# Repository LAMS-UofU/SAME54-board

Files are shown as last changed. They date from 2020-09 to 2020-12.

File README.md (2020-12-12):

# LAMS 

In these files, you will find the software, datasheets and PCB design for the LAMS project. We integrated multiple peripherals to use with our needed devices such as: timers for the servo PWM signal, UART communications for the LiDAR, simple GPIO signals for a status LED, as well as a simple SysTick configuration to give precise timing measurements. 

## Pinouts

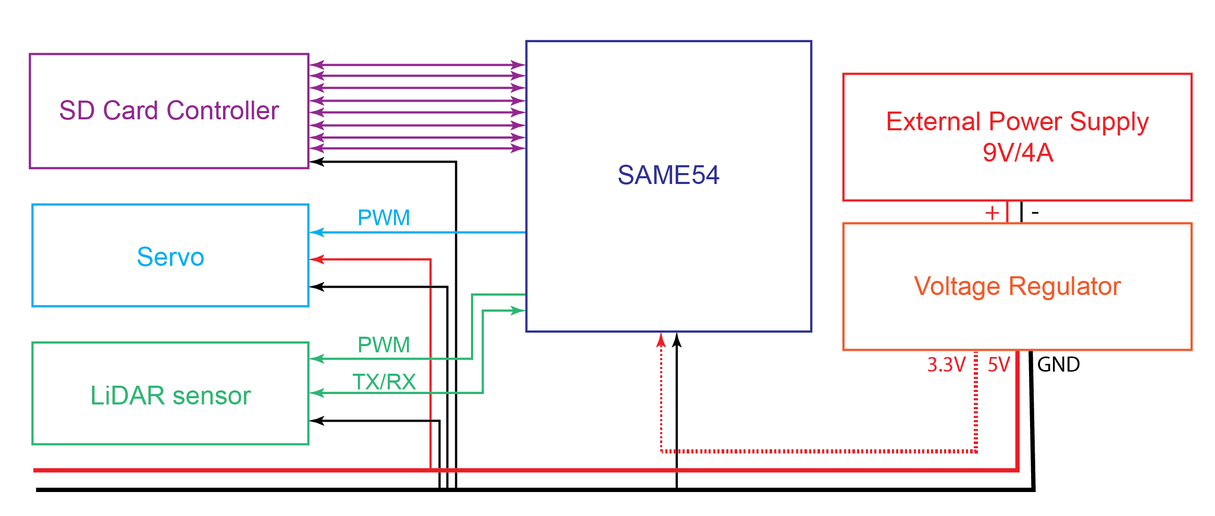
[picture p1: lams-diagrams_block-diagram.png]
Block Diagram


LiDAR: Tx (PA04) / Rx (PA05) / PWM (PB09) <br>
Servo: PWM (PA07) <br>
SD Card: CMD (PA20) / CLK (PA21) / DAT0 (PB18) / DAT1 (PB19) / DAT2 (PB20) / DAT3 (PB21) / CD (PD20) / WP (PD21) <br>
Status LED: PA06 <br>
Start Button: PA27 <br>

## Resources

### SAME54

[SAM D5X/E5X Family Datasheet](http://ww1.microchip.com/downloads/en/DeviceDoc/SAM_D5xE5x_Family_Data_Sheet_DS60001507F.pdf) <br>
[SAM E54 Xplained Pro User's Guide](http://ww1.microchip.com/downloads/en/DeviceDoc/70005321A.pdf)

### Peripherals

[RPLiDAR A2M8 Datasheet](https://cdn.sparkfun.com/assets/e/a/f/9/8/LD208_SLAMTEC_rplidar_datasheet_A2M8_v1.0_en.pdf) <br>
[RPLiDAR A2M8 Communications Protocol v1.0](https://www.robotshop.com/media/files/pdf2/rpk-02-communication-protocol.pdf) <br>
[RPLiDAR A2M8 Communications Protocol v2.1](http://bucket.download.slamtec.com/ccb3c2fc1e66bb00bd4370e208b670217c8b55fa/LR001_SLAMTEC_rplidar_protocol_v2.1_en.pdf) <br>
[SPT5435-180 Specifications](http://www.spt-servo.com/Product/015234339.html)

### MISC

[ASF4 API Reference Manual](http://ww1.microchip.com/downloads/en/DeviceDoc/50002633B.pdf)

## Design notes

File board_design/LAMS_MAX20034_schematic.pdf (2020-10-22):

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

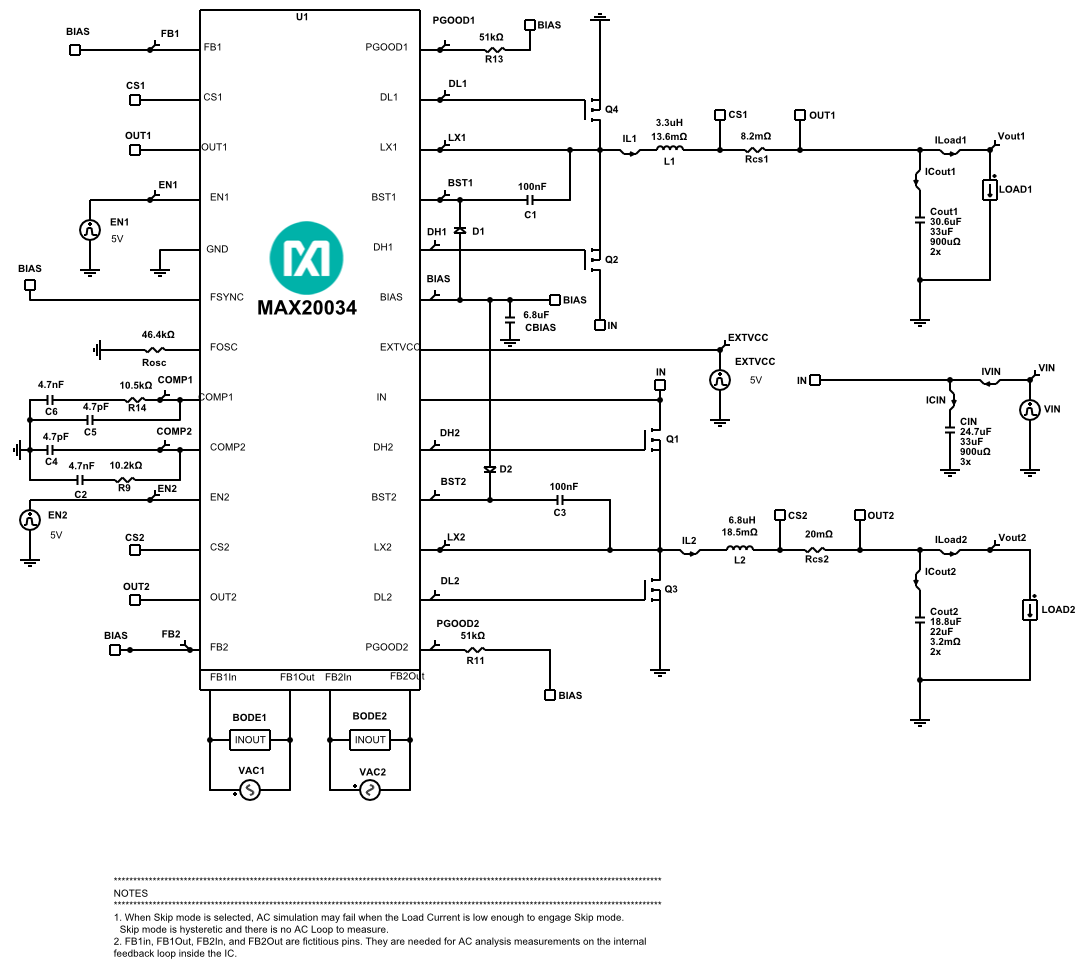
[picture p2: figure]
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

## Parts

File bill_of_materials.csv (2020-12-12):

Ref Part | Quantity | Mouser Part # | Manufacturer Part # | Manufacturer | Description
IC1 | 1 | 556-ATSAME54N20AAUT | ATSAME54N20A-AUT | Microchip | ARM Microcontrollers - MCU 120MHZ 1024KB FLASH 100 TQFP PKG IN 85C
U1 | 1 | 700-MAX20034ATIR/VY+ | MAX20034ATIR/VY+ | Maxim Integrated | 2.2MHz, 36V, Dual Buck Controller with 17Î¼A Quiescent Current
OSC1 | 1 | 581-CX3225CA12DKPSC1 | CX3225CA12000D0KPSC1. | Kyocera | Crystals 12MHz 8pF 3.2x2.5x0.8mm
J1 | 1 | 490-PJ-070BH-SMT-TR | PJ-070BH-SMT-TR | CUI Devices | DC Power Connectors power jack, 2.5 x 5.5 mm, vertical, SMT, high current, 1 switch, T&R package
SD_CARD_CONN | 1 | 523-GSD09002SEU | GSD09002SEU | Amphenol | Memory Card Connectors SD, 9 pos, 15U
RESET_BTN, START_BTN | 2 | 612-LL3301BF065QJ | LL3301BF065QJ | E-Switch | Pushbutton Switches 50mA 12VDC F065 9.5mm J-Lead
C5,C6,C7,C8,C10,C11,C15,C16 | 8 | 80-C0603C104K5R | C0603C104K5RACTU | KEMET Corporation | Cap Ceramic 100nF 50V X7R 10% Pad SMD 0603 125Â°C T/R
C1,C4 | 2 | 80-C0603C472J5R | C0603C472J5RACTU | KEMET Corporation | Cap Ceramic 4.7nF 50V X7R 5% Pad SMD 0603 125Â°C T/R
C2,C3 | 2 | 581-04025A4R7JAT2A | 04025A4R7JAT2A | AVX | Cap Ceramic 4.7pF 50V C0G 5% Pad SMD 0402 125Â°C T/R
C9 | 1 | 81-GRM188R61E106KA3D | GRM188R61E106KA73D | Murata Electronics | Multilayer Ceramic Capacitors MLCC - SMD/SMT 10UF 25V 10% 0603
C12,C13 | 2 | 81-GRM1885C1H8R0CA1D | GRM1885C1H8R0CA01D | Murata Electronics | Multilayer Ceramic Capacitors MLCC - SMD/SMT 8pF 0603
C14 | 1 | 81-GRM188R61C475KAJD | GRM188R61C475KAAJD | Murata Electronics | Multilayer Ceramic Capacitors MLCC - SMD/SMT 0603 4.7uF 16volts *Derate Voltage/Temp
CBIAS | 1 | 80-C1206C685K4R | C1206C685K4RACTU | KEMET Corporation | Cap Ceramic 6.8uF 16V X7R 10% Pad SMD 1206 125Â°C T/R
COUT1, CIN | 5 | 810-C4532X7R1C336M | C4532X7R1C336M250KC | TDK | Multilayer Ceramic Capacitors MLCC - SMD/SMT 1812 16V 33uF X7R 20% T: 2.5mm
COUT2 | 2 | 81-GRM31CR71A226ME5L | GRM31CR71A226ME15L | Murata Manufacturing | Cap 22uF 10V X7R 1206 20% 3.2mOhm 0.72nH Active
D1,D2 | 2 | 863-MBRS140T3G | MBRS140T3G | ON Semiconductor | Rectifier Diode Schottky Si 40V 1A 2-Pin SMB T/R
LED_STATUS | 1 | 710-155060VS75300 | 155060VS75300 | Wurth Elektronik | Standard LEDs - SMD WL-SMSW Wtrclr SdVw Grn 2V 20mA 572nm
LED_RX,LED_TX | 2 | 710-155060AS75300 | 155060VS75301 | Wurth Elektronik | Standard LEDs - SMD WL-SMSW Wtrclr SdVw Amber 2V 20mA 610nm
L1 | 1 | 652-SRP1238A-3R3M | SRP1238A-3R3M | Bourns | Fixed Inductors 3.3uH 20% SMD 1238 AEC-Q200
L2 | 1 | 994-MSS1260-682MLB | MSS1260-682MLB | Coilcraft | Inductor 6.8 uH 20% 18.5mOhm max 3.8Arms @20C 5.9Arms @40C 7.4Asat @-10% 8.26Asat @-20% 8.8Asat @-30% 6.2mmHt 151.29mm^2 MSS1260 Active
M1,M2,M3,M4 | 4 | 863-NVMFS5C468NLFT1G | NVMFS5C468NLAFT1G | On Semi | MOSFET T6 40V NCH LL IN SO8FL
R1 | 1 | 667-ERJ-2RKF1022X | ERJ-2RKF1022X | Panasonic | Res Thick Film 0402 10.2K Ohm 1% 0.1W(1/10W) Â±100ppm/Â°C Pad SMD Automotive T/R
R3,R4 | 2 | 667-ERJ-2GEJ513X | ERJ2GEJ513X | Panasonic | Res Thick Film 0402 51K Ohm 5% 0.1W(1/10W) Â±200ppm/Â°C Pad SMD Automotive T/R
R2 | 1 | 667-ERJ-2RKF1052X | ERJ2RKF1052X | Panasonic | Res Thick Film 0402 10.5K Ohm 1% 0.1W(1/10W) Â±100ppm/Â°C Pad SMD Automotive T/R
R5 | 1 | 667-ERJ-UP3F3300V | ERJ-UP3F3300V | Panasonic | Thick Film Resistors - SMD 0603 0.25W 1% 330ohm AEC-Q200
R6,R8,R12,R13,R15 | 5 | 667-ERJ-UP3F1002V | ERJ-UP3F1002V | Panasonic | Thick Film Resistors - SMD 0603 0.25W 1% 10Kohm AEC-Q200
R7,R9,R10,R11 | 4 | 667-ERJ-PA3F1003V | ERJ-PA3F1003V | Panasonic | Thick Film Resistors - SMD 0603 100Kohm 1% Anti-Surge AEC-Q200
R14 | 1 | 667-ERJ-PA3F1001V | ERJ-PA3F1001V | Panasonic | Thick Film Resistors - SMD 0603 1Kohm 1% Anti-Surge AEC-Q200
R16,R17,R18 | 3 | 667-ERJ-UP3J101V | ERJ-UP3J101V | Panasonic | Thick Film Resistors - SMD 0603 0.25W 5% 100ohm AEC-Q200
RCS1 | 1 | 667-ERJ-3LWFR010V | ERJ-3LWFR010V | Panasonic | Current Sense Resistors - SMD 0603 10mOhms 1% Curr Sens AEC-Q200
RCS2 | 1 | 667-ERJ-8BWFR020V | ERJ8BWFR020V | Panasonic | Res Thick Film 1206 0.02 Ohm 1% 1W 0ppm/Â°C to 150ppm/Â°C Pad SMD Automotive T/R
ROSC | 1 | 667-ERJ-2RKF4642X | ERJ2RKF4642X | Panasonic | Res Thick Film 0402 46.4K Ohm 1% 0.1W(1/10W) Â±100ppm/Â°C Pad SMD Automotive T/R

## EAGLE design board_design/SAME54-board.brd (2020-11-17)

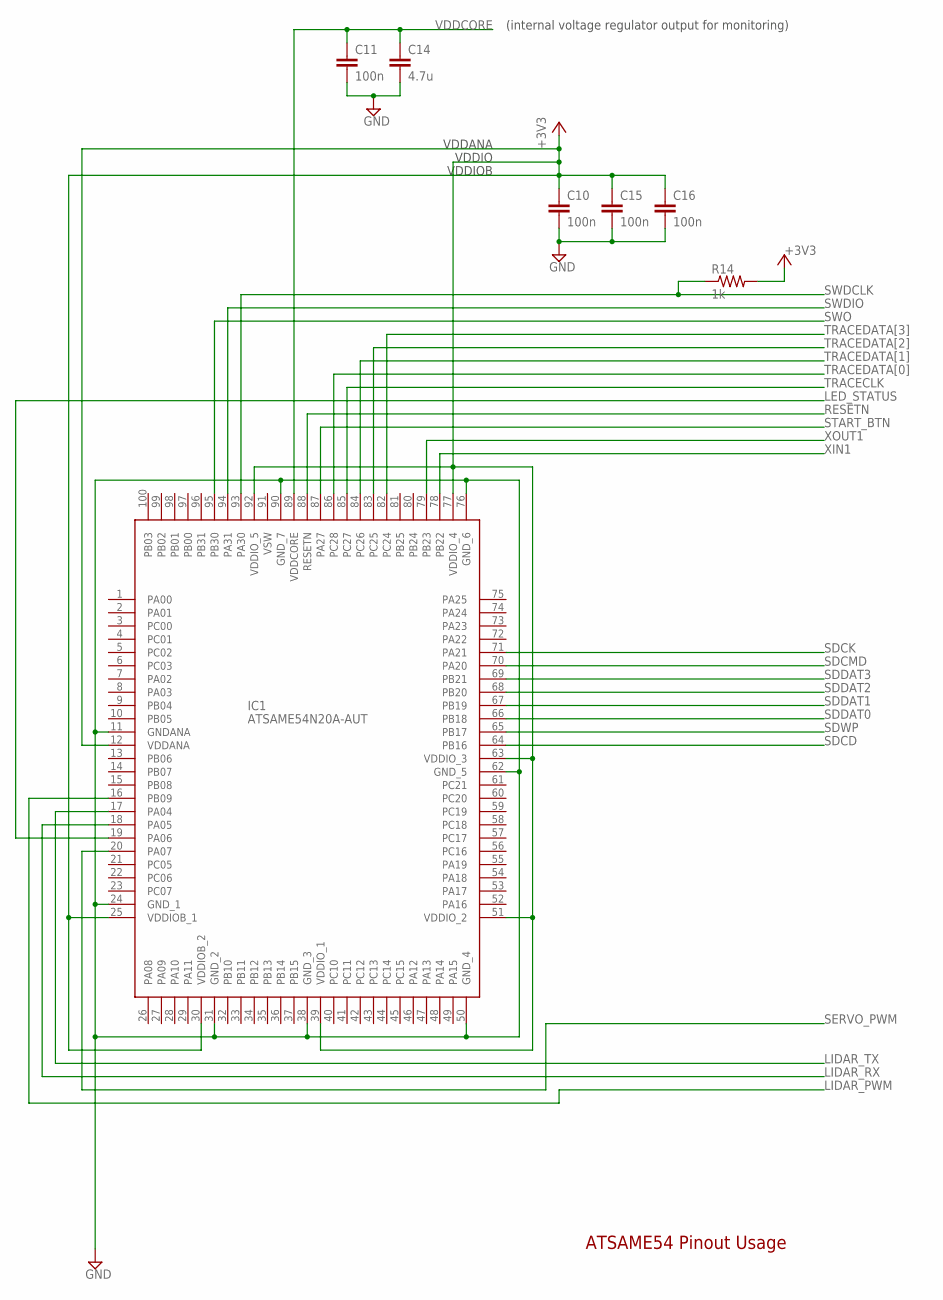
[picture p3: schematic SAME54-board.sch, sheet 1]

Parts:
C10, C11, C15, C16: 100n; C0603
C14: 4.7u; C0603
IC1: ATSAME54N20A-AUT; QFP50P1600X1600X120-100N
R14: 1k; R0603

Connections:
+3V3: C10.1, C15.1, C16.1, IC1.12 (VDDANA), IC1.25 (VDDIOB_1), IC1.30 (VDDIOB_2), IC1.39 (VDDIO_1), IC1.51 (VDDIO_2), IC1.63 (VDDIO_3), IC1.77 (VDDIO_4), IC1.92 (VDDIO_5), R14.2; also elsewhere on the board
GND: C10.2, C11.2, C14.2, C15.2, C16.2, IC1.11 (GNDANA), IC1.24 (GND_1), IC1.31 (GND_2), IC1.38 (GND_3), IC1.50 (GND_4), IC1.62 (GND_5), IC1.76 (GND_6), IC1.90 (GND_7); also elsewhere on the board
LED_STATUS: IC1.19 (PA06); also elsewhere on the board
LIDAR_PWM: IC1.16 (PB09); also elsewhere on the board
LIDAR_RX: IC1.18 (PA05); also elsewhere on the board
LIDAR_TX: IC1.17 (PA04); also elsewhere on the board
RESETN: IC1.88 (RESETN); also elsewhere on the board
SDCD: IC1.64 (PB16); also elsewhere on the board
SDCK: IC1.71 (PA21); also elsewhere on the board
SDCMD: IC1.70 (PA20); also elsewhere on the board
SDDAT0: IC1.66 (PB18); also elsewhere on the board
SDDAT1: IC1.67 (PB19); also elsewhere on the board
SDDAT2: IC1.68 (PB20); also elsewhere on the board
SDDAT3: IC1.69 (PB21); also elsewhere on the board
SDWP: IC1.65 (PB17); also elsewhere on the board
SERVO_PWM: IC1.20 (PA07); also elsewhere on the board
START_BTN: IC1.87 (PA27); also elsewhere on the board
SWDCLK: IC1.93 (PA30), R14.1; also elsewhere on the board
SWDIO: IC1.94 (PA31); also elsewhere on the board
SWO: IC1.95 (PB30); also elsewhere on the board
TRACECLK: IC1.85 (PC27); also elsewhere on the board
TRACEDATA[0]: IC1.86 (PC28); also elsewhere on the board
TRACEDATA[1]: IC1.84 (PC26); also elsewhere on the board
TRACEDATA[2]: IC1.83 (PC25); also elsewhere on the board
TRACEDATA[3]: IC1.82 (PC24); also elsewhere on the board
VDDCORE: C11.1, C14.1, IC1.89 (VDDCORE)
XIN1: IC1.78 (PB22); also elsewhere on the board
XOUT1: IC1.79 (PB23); also elsewhere on the board

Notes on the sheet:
ATSAME54 Pinout Usage
(internal voltage regulator output for monitoring)
VDDANA
VDDIO
VDDIOB

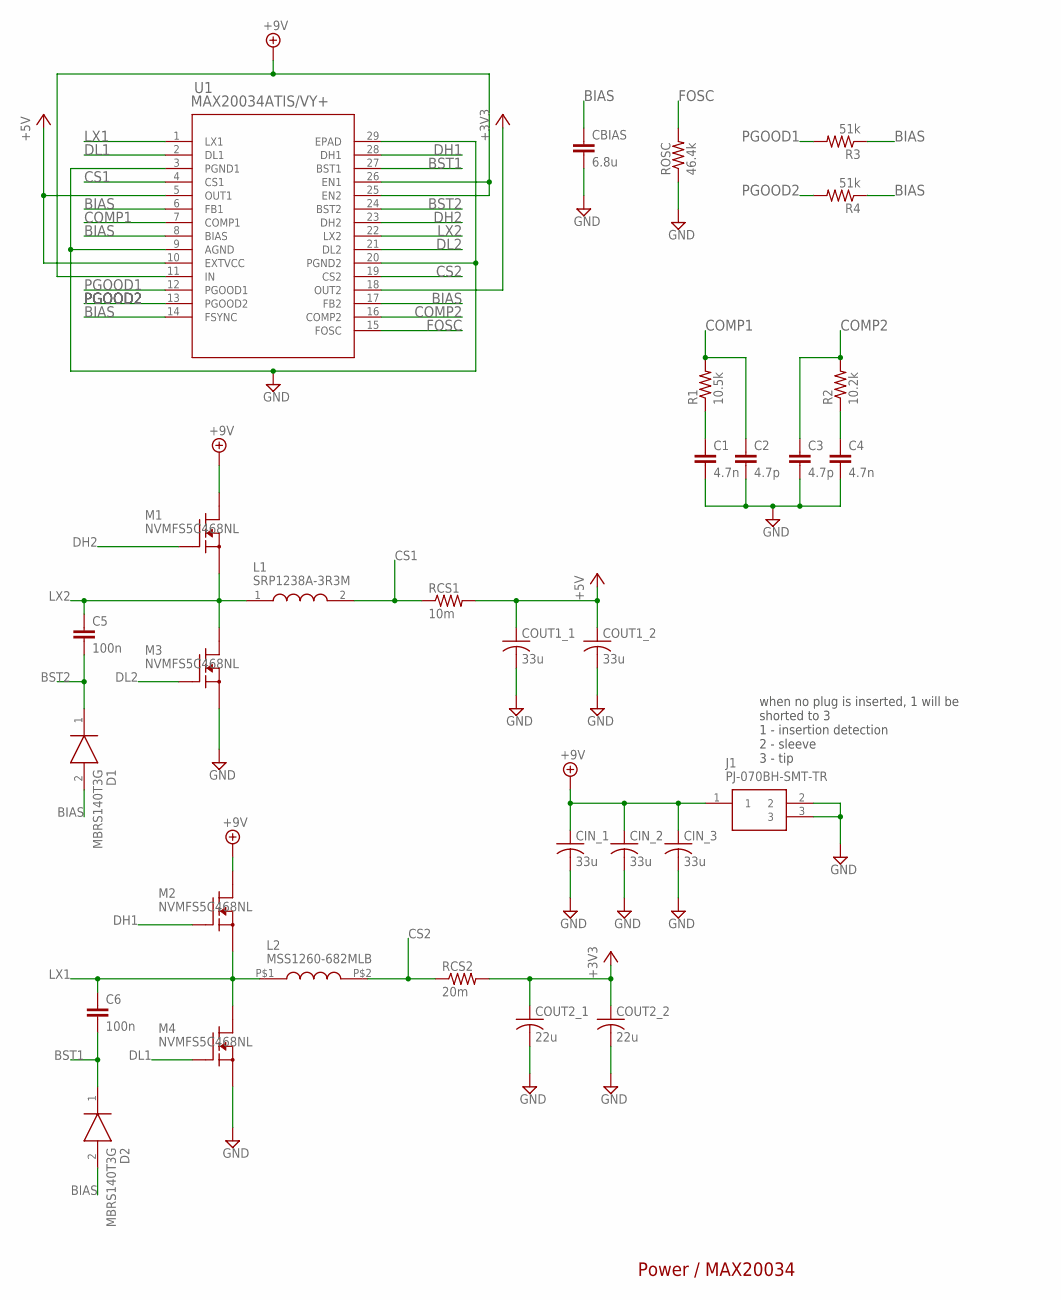
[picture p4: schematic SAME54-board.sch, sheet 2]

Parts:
C1, C4: 4.7n; C0603
C2, C3: 4.7p; C0402
C5, C6: 100n; C0603
CBIAS: 6.8u; C1206
CIN_1, CIN_2, CIN_3: 33u; C1812
COUT1_1, COUT1_2: 33u; C1812
COUT2_1, COUT2_2: 22u; C1206
D1, D2: MBRS140T3G; DIOM5436X247N
J1: PJ-070BH-SMT-TR; PJ070BHSMTTR
L1: SRP1238A-3R3M; INDPM135125X350N
L2: MSS1260-682MLB; MSS1260
M1, M2, M3, M4: NVMFS5C468NL; DFN5_SO-8FL
R1: 10.5k; R0402
R2: 10.2k; R0402
R3, R4: 51k; R0402
RCS1: 10m; R0603
RCS2: 20m; R1206
ROSC: 46.4k; R0402
U1: MAX20034ATIS/VY+; 21-100130_MXM

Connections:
+3V3: COUT2_1.1, COUT2_2.1, RCS2.2, U1.18 (OUT2); also elsewhere on the board
+5V: COUT1_1.1, COUT1_2.1, RCS1.2, U1.5 (OUT1), U1.10 (EXTVCC); also elsewhere on the board
+9V: CIN_1.1, CIN_2.1, CIN_3.1, J1.1, M1.D1 (D), M1.D2 (D), M1.D3 (D), M1.D4 (D), M2.D1 (D), M2.D2 (D), M2.D3 (D), M2.D4 (D), U1.11 (IN), U1.25 (EN2), U1.26 (EN1)
BIAS: CBIAS.1, D1.2 (A), D2.2 (A), R3.1, R4.1, U1.6 (FB1), U1.8 (BIAS), U1.14 (FSYNC), U1.17 (FB2)
BST1: C6.2, D2.1 (K), U1.27 (BST1)
BST2: C5.2, D1.1 (K), U1.24 (BST2)
COMP1: C2.1, R1.2, U1.7 (COMP1)
COMP2: C3.1, R2.2, U1.16 (COMP2)
CS1: L1.2, RCS1.1, U1.4 (CS1)
CS2: L2.P$2 (2), RCS2.1, U1.19 (CS2)
DH1: M2.G, U1.28 (DH1)
DH2: M1.G, U1.23 (DH2)
DL1: M4.G, U1.2 (DL1)
DL2: M3.G, U1.21 (DL2)
FOSC: ROSC.2, U1.15 (FOSC)
GND: C1.2, C2.2, C3.2, C4.2, CBIAS.2, CIN_1.2, CIN_2.2, CIN_3.2, COUT1_1.2, COUT1_2.2, COUT2_1.2, COUT2_2.2, J1.2, J1.3, M3.S1 (S), M3.S2 (S), M3.S3 (S), M4.S1 (S), M4.S2 (S), M4.S3 (S), ROSC.1, U1.3 (PGND1), U1.9 (AGND), U1.20 (PGND2), U1.29 (EPAD); also elsewhere on the board
LX1: C6.1, L2.P$1 (1), M2.S1 (S), M2.S2 (S), M2.S3 (S), M4.D1 (D), M4.D2 (D), M4.D3 (D), M4.D4 (D), U1.1 (LX1)
LX2: C5.1, L1.1, M1.S1 (S), M1.S2 (S), M1.S3 (S), M3.D1 (D), M3.D2 (D), M3.D3 (D), M3.D4 (D), U1.22 (LX2)
unnamed: C1.1, R1.1
unnamed: C4.1, R2.1
PGOOD1: R3.2, U1.12 (PGOOD1)
PGOOD2: R4.2, U1.13 (PGOOD2)

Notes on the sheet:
Power / MAX20034
when no plug is inserted, 1 will be shorted to 3 1 - insertion detection 2 - sleeve 3 - tip

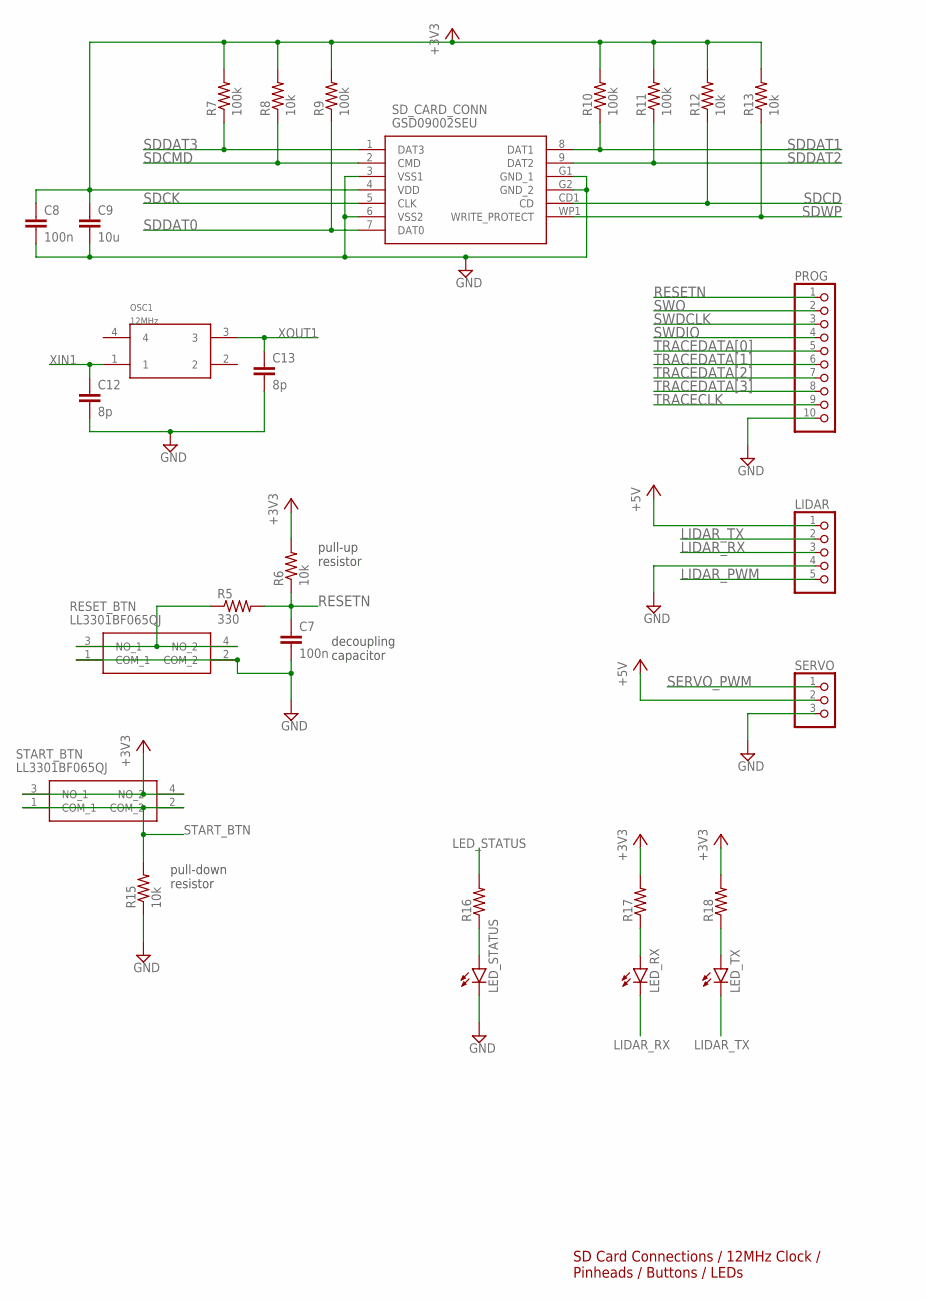
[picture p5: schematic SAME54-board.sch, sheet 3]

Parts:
C7, C8: 100n; C0603
C9: 10u; C0603
C12, C13: 8p; C0603
LED_RX: LEDCHIPLED_0603; CHIPLED_0603
LED_STATUS: LEDCHIPLED_0603; CHIPLED_0603
LED_TX: LEDCHIPLED_0603; CHIPLED_0603
LIDAR: PINHD-1X5; 1X05
OSC1: CX3225CA12000D0KPSC1CX3225CA; OSCCC320X250X90N
PROG: PINHD-1X10; 1X10
R5: 330; R0603
R6, R8, R12, R13, R15: 10k; R0603
R7, R9, R10, R11: 100k; R0603
R16, R17, R18: R-US_R0603; R0603
RESET_BTN: LL3301BF065QJ
SD_CARD_CONN: GSD09002SEU
SERVO: PINHD-1X3; 1X03
START_BTN: LL3301BF065QJ

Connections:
+3V3: C8.1, C9.1, R6.2, R7.2, R8.2, R9.2, R10.2, R11.2, R12.2, R13.2, R17.2, R18.2, SD_CARD_CONN.4 (VDD), START_BTN.3 (NO_1), START_BTN.4 (NO_2); also elsewhere on the board
+5V: LIDAR.1, SERVO.2; also elsewhere on the board
GND: C7.2, C8.2, C9.2, C12.2, C13.2, LED_STATUS.C, LIDAR.4, PROG.10, R15.1, RESET_BTN.1 (COM_1), RESET_BTN.2 (COM_2), SD_CARD_CONN.3 (VSS1), SD_CARD_CONN.6 (VSS2), SD_CARD_CONN.G1 (GND_1), SD_CARD_CONN.G2 (GND_2), SERVO.3; also elsewhere on the board
LED_STATUS: R16.2; also elsewhere on the board
LIDAR_PWM: LIDAR.5; also elsewhere on the board
LIDAR_RX: LED_RX.C, LIDAR.3; also elsewhere on the board
LIDAR_TX: LED_TX.C, LIDAR.2; also elsewhere on the board
unnamed: LED_STATUS.A, R16.1
unnamed: R5.1, RESET_BTN.3 (NO_1), RESET_BTN.4 (NO_2)
unnamed: LED_RX.A, R17.1
unnamed: LED_TX.A, R18.1
RESETN: C7.1, PROG.1, R5.2, R6.1; also elsewhere on the board
SDCD: R12.1, SD_CARD_CONN.CD1 (CD); also elsewhere on the board
SDCK: SD_CARD_CONN.5 (CLK); also elsewhere on the board
SDCMD: R8.1, SD_CARD_CONN.2 (CMD); also elsewhere on the board
SDDAT0: R9.1, SD_CARD_CONN.7 (DAT0); also elsewhere on the board
SDDAT1: R10.1, SD_CARD_CONN.8 (DAT1); also elsewhere on the board
SDDAT2: R11.1, SD_CARD_CONN.9 (DAT2); also elsewhere on the board
SDDAT3: R7.1, SD_CARD_CONN.1 (DAT3); also elsewhere on the board
SDWP: R13.1, SD_CARD_CONN.WP1 (WRITE_PROTECT); also elsewhere on the board
SERVO_PWM: SERVO.1; also elsewhere on the board
START_BTN: R15.2, START_BTN.1 (COM_1), START_BTN.2 (COM_2); also elsewhere on the board
SWDCLK: PROG.3; also elsewhere on the board
SWDIO: PROG.4; also elsewhere on the board
SWO: PROG.2; also elsewhere on the board
TRACECLK: PROG.9; also elsewhere on the board
TRACEDATA[0]: PROG.5; also elsewhere on the board
TRACEDATA[1]: PROG.6; also elsewhere on the board
TRACEDATA[2]: PROG.7; also elsewhere on the board
TRACEDATA[3]: PROG.8; also elsewhere on the board
XIN1: C12.1, OSC1.1; also elsewhere on the board
XOUT1: C13.1, OSC1.3; also elsewhere on the board

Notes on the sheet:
SD Card Connections / 12MHz Clock / Pinheads / Buttons / LEDs
decoupling capacitor
pull-up resistor
pull-down resistor

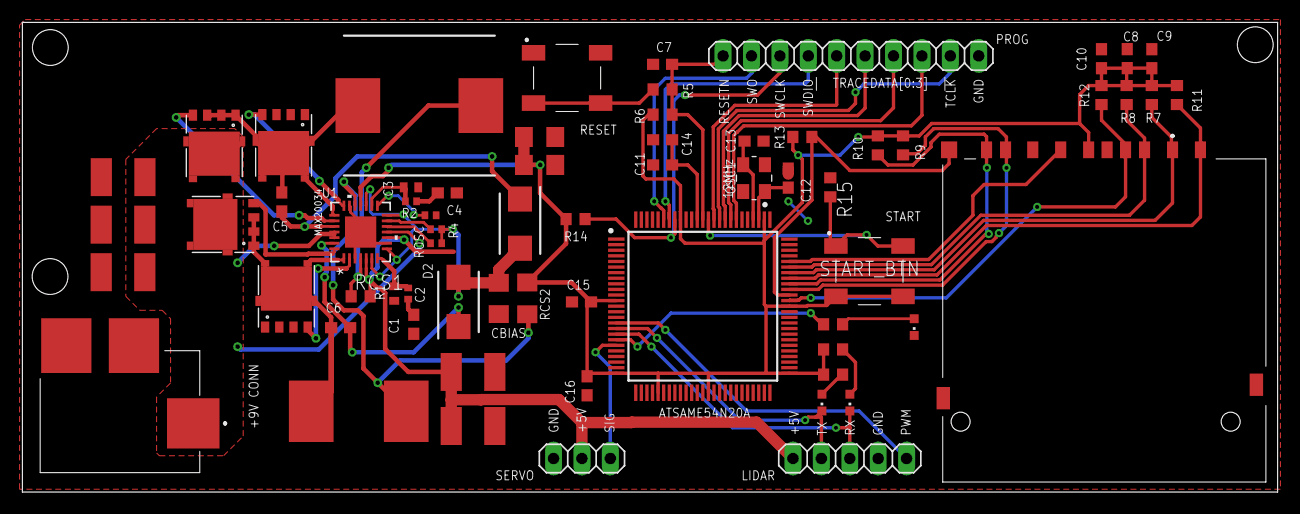
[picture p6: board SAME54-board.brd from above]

Board: 2 copper layers, 112.2 x 42.0 mm, 66 parts (0 on the bottom side), 52 nets.

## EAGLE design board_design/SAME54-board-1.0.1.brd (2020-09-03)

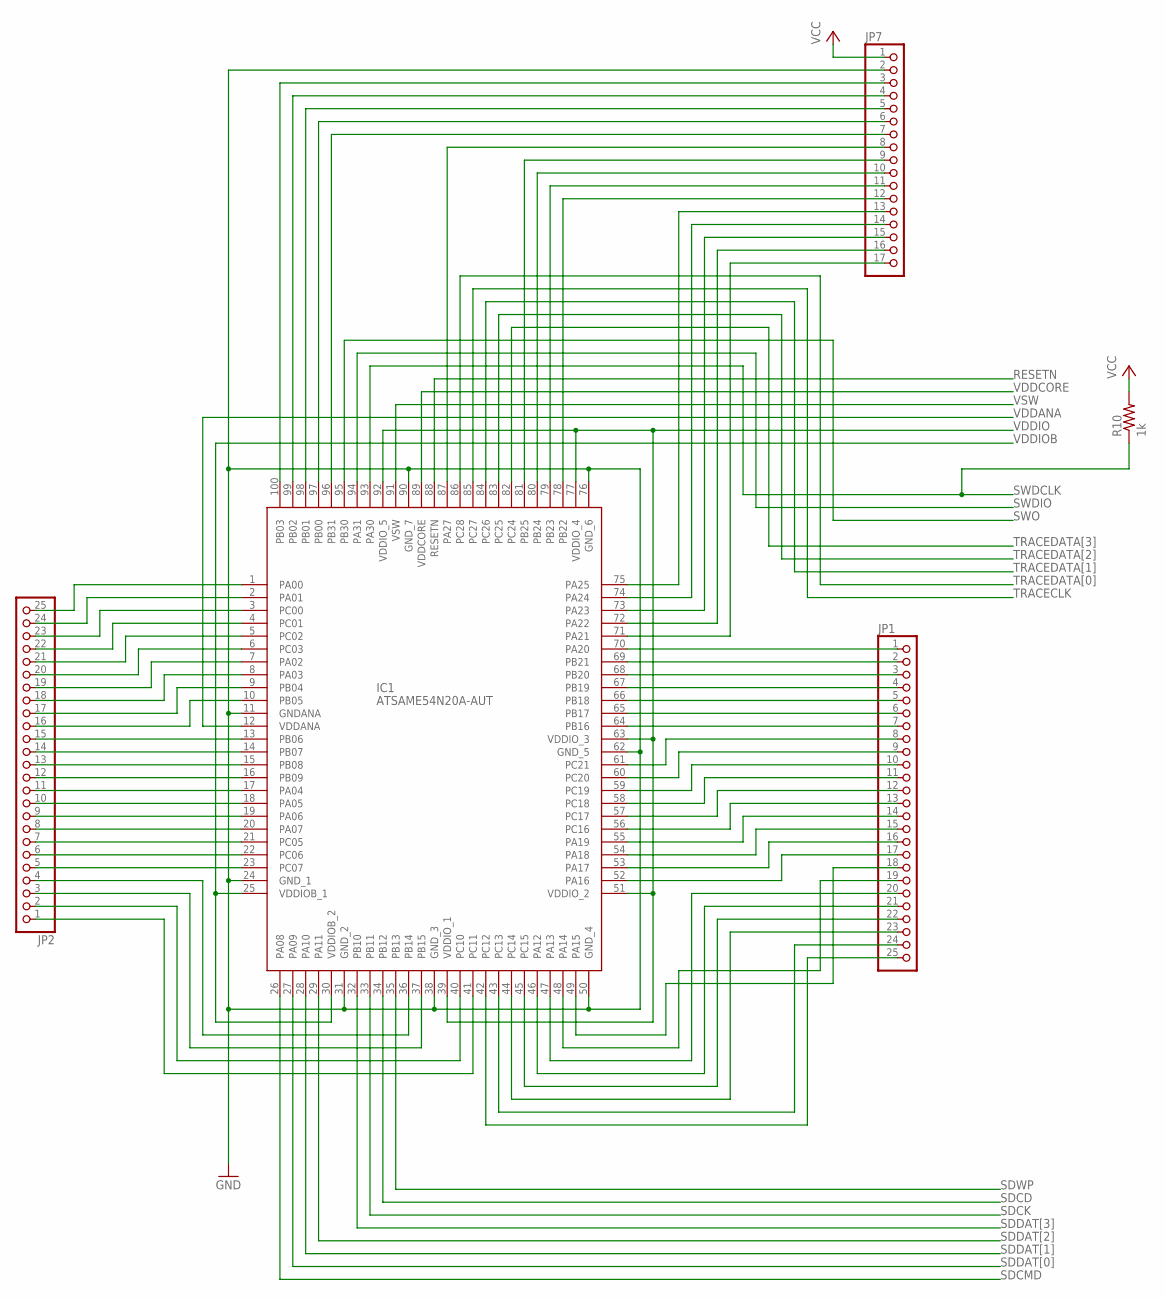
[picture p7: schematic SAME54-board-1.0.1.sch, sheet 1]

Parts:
IC1: ATSAME54N20A-AUT; QFP50P1600X1600X120-100N
JP1, JP2: PINHD-1X25; 1X25
JP7: PINHD-1X17; 1X17
R10: 1k; M1206

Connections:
GND: IC1.11 (GNDANA), IC1.24 (GND_1), IC1.31 (GND_2), IC1.38 (GND_3), IC1.50 (GND_4), IC1.62 (GND_5), IC1.76 (GND_6), IC1.90 (GND_7), JP7.2; also elsewhere on the board
unnamed: IC1.23 (PC07), JP2.5
unnamed: IC1.22 (PC06), JP2.6
unnamed: IC1.21 (PC05), JP2.7
unnamed: IC1.20 (PA07), JP2.8
unnamed: IC1.19 (PA06), JP2.9
unnamed: IC1.18 (PA05), JP2.10
unnamed: IC1.17 (PA04), JP2.11
unnamed: IC1.16 (PB09), JP2.12
unnamed: IC1.15 (PB08), JP2.13
unnamed: IC1.14 (PB07), JP2.14
unnamed: IC1.13 (PB06), JP2.15
unnamed: IC1.10 (PB05), JP2.16
unnamed: IC1.9 (PB04), JP2.17
unnamed: IC1.8 (PA03), JP2.18
unnamed: IC1.7 (PA02), JP2.19
unnamed: IC1.6 (PC03), JP2.20
unnamed: IC1.5 (PC02), JP2.21
unnamed: IC1.4 (PC01), JP2.22
unnamed: IC1.3 (PC00), JP2.23
unnamed: IC1.2 (PA01), JP2.24
unnamed: IC1.73 (PA23), JP7.15
unnamed: IC1.70 (PA20), JP1.1
unnamed: IC1.69 (PB21), JP1.2
unnamed: IC1.68 (PB20), JP1.3
unnamed: IC1.67 (PB19), JP1.4
unnamed: IC1.66 (PB18), JP1.5
unnamed: IC1.65 (PB17), JP1.6
unnamed: IC1.64 (PB16), JP1.7
unnamed: IC1.61 (PC21), JP1.8
unnamed: IC1.60 (PC20), JP1.9
unnamed: IC1.59 (PC19), JP1.10
unnamed: IC1.58 (PC18), JP1.11
unnamed: IC1.57 (PC17), JP1.12
unnamed: IC1.56 (PC16), JP1.13
unnamed: IC1.55 (PA19), JP1.14
unnamed: IC1.54 (PA18), JP1.15
unnamed: IC1.53 (PA17), JP1.16
unnamed: IC1.52 (PA16), JP1.17
unnamed: IC1.49 (PA15), JP1.18
unnamed: IC1.48 (PA14), JP1.19
unnamed: IC1.41 (PC11), JP2.1
unnamed: IC1.47 (PA13), JP1.20
unnamed: IC1.46 (PA12), JP1.21
unnamed: IC1.45 (PC15), JP1.22
unnamed: IC1.44 (PC14), JP1.23
unnamed: IC1.43 (PC13), JP1.24
unnamed: IC1.42 (PC12), JP1.25
unnamed: IC1.40 (PC10), JP2.2
unnamed: IC1.37 (PB15), JP2.3
unnamed: IC1.36 (PB14), JP2.4
unnamed: IC1.1 (PA00), JP2.25
PA21: IC1.71 (PA21), JP7.17
PA22: IC1.72 (PA22), JP7.16
PA24: IC1.74 (PA24), JP7.14
PA25: IC1.75 (PA25), JP7.13
PA27: IC1.87 (PA27), JP7.8
PB0: IC1.97 (PB00), JP7.6
PB1: IC1.98 (PB01), JP7.5
PB2: IC1.99 (PB02), JP7.4
PB3: IC1.100 (PB03), JP7.3
PB22: IC1.78 (PB22), JP7.12
PB23: IC1.79 (PB23), JP7.11
PB24: IC1.80 (PB24), JP7.10
PB25: IC1.81 (PB25), JP7.9
PB31: IC1.96 (PB31), JP7.7
RESETN: IC1.88 (RESETN); also elsewhere on the board
SDCD: IC1.34 (PB12); also elsewhere on the board
SDCK: IC1.33 (PB11); also elsewhere on the board
SDCMD: IC1.26 (PA08)
SDDAT[0]: IC1.27 (PA09); also elsewhere on the board
SDDAT[1]: IC1.28 (PA10); also elsewhere on the board
SDDAT[2]: IC1.29 (PA11); also elsewhere on the board
SDDAT[3]: IC1.32 (PB10); also elsewhere on the board
SDWP: IC1.35 (PB13); also elsewhere on the board
SWDCLK: IC1.93 (PA30), R10.1; also elsewhere on the board
SWDIO: IC1.94 (PA31); also elsewhere on the board
SWO: IC1.95 (PB30); also elsewhere on the board
TRACECLK: IC1.85 (PC27); also elsewhere on the board
TRACEDATA[0]: IC1.86 (PC28); also elsewhere on the board
TRACEDATA[1]: IC1.84 (PC26); also elsewhere on the board
TRACEDATA[2]: IC1.83 (PC25); also elsewhere on the board
TRACEDATA[3]: IC1.82 (PC24); also elsewhere on the board
VCC: JP7.1, R10.2; also elsewhere on the board
VDDANA: IC1.12 (VDDANA); also elsewhere on the board
VDDCORE: IC1.89 (VDDCORE); also elsewhere on the board
VDDIO: IC1.39 (VDDIO_1), IC1.51 (VDDIO_2), IC1.63 (VDDIO_3), IC1.77 (VDDIO_4), IC1.92 (VDDIO_5); also elsewhere on the board
VDDIOB: IC1.25 (VDDIOB_1), IC1.30 (VDDIOB_2); also elsewhere on the board
VSW: IC1.91 (VSW); also elsewhere on the board

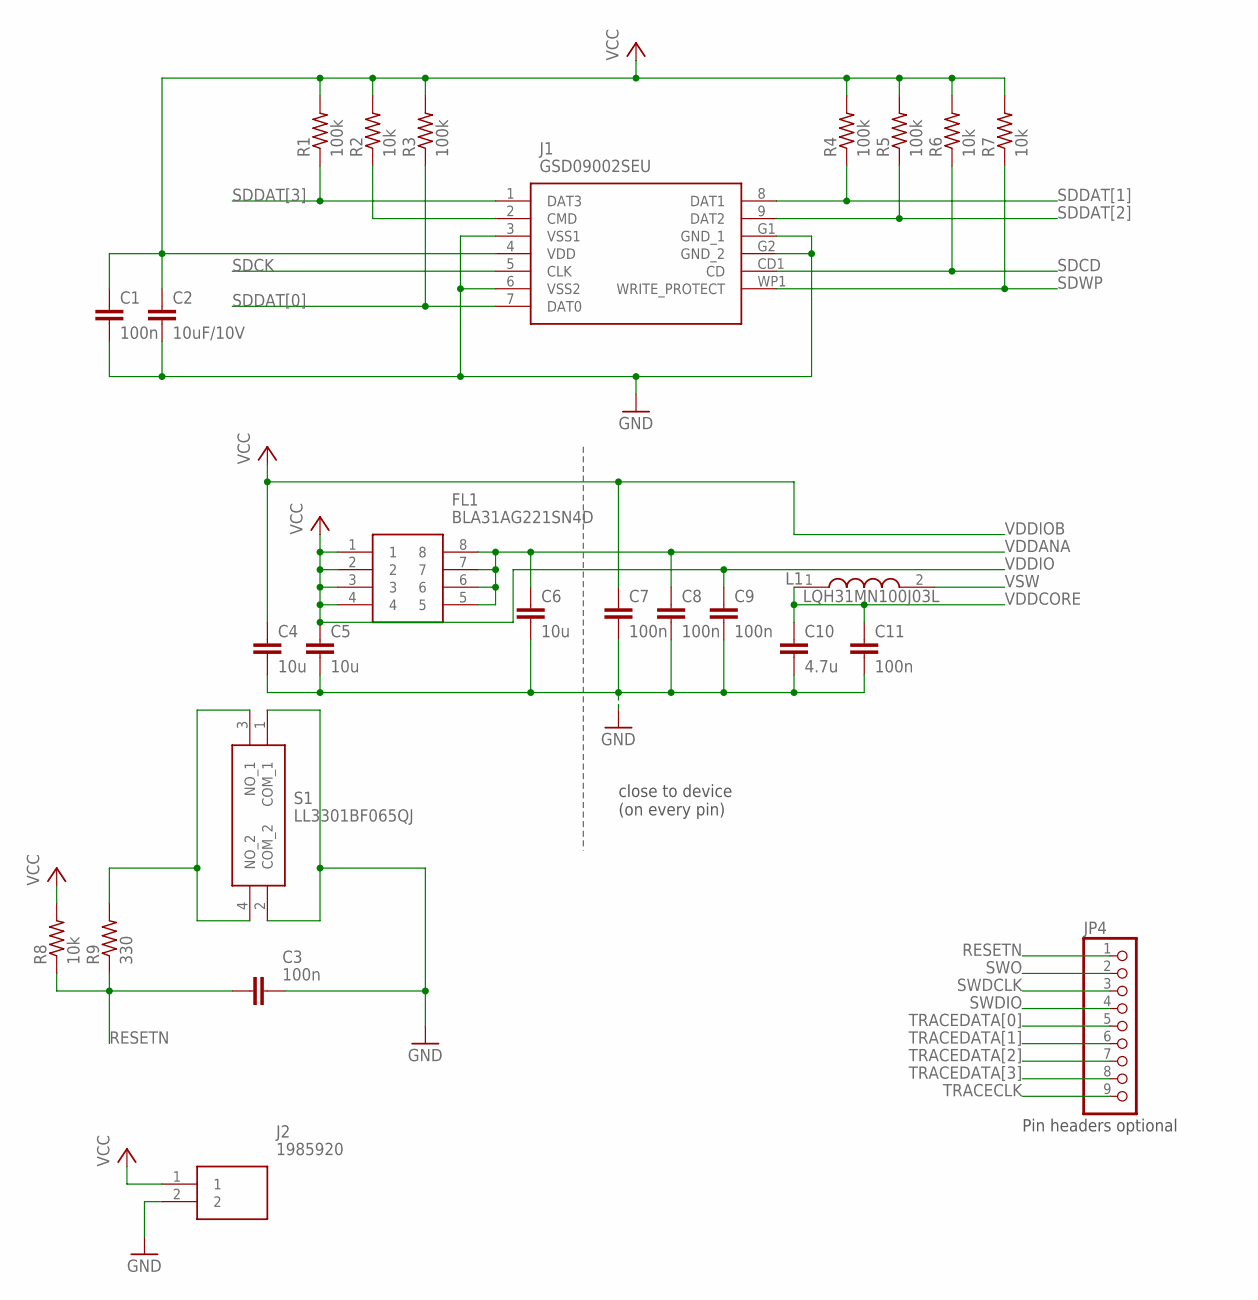
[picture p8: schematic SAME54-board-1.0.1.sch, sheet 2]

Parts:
C1, C3, C7, C8, C9, C11: 100n; C1206
C2: 10uF/10V; C1206
C4, C5, C6: 10u; C1206
C10: 4.7u; C1206
FL1: BLA31AG221SN4D; BLA31AG102SN4D
J1: GSD09002SEU
J2: 1985920; SHDR2W110P0X500_1X2_1000X950X1
JP4: PINHD-1X9; 1X09
L1: LQH31MN100J03L; LQH31CN100K03L
R1, R3, R4, R5: 100k; M1206
R2, R6, R7, R8: 10k; M1206
R9: 330; M1206
S1: LL3301BF065QJ

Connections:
GND: C1.2, C2.2, C3.2, C4.2, C5.2, C6.2, C7.2, C8.2, C9.2, C10.2, C11.2, J1.3 (VSS1), J1.6 (VSS2), J1.G1 (GND_1), J1.G2 (GND_2), J2.2, S1.1 (COM_1), S1.2 (COM_2); also elsewhere on the board
unnamed: J1.2 (CMD), R2.1
unnamed: R9.2, S1.3 (NO_1), S1.4 (NO_2)
RESETN: C3.1, JP4.1, R8.1, R9.1; also elsewhere on the board
SDCD: J1.CD1 (CD), R6.1; also elsewhere on the board
SDCK: J1.5 (CLK); also elsewhere on the board
SDDAT[0]: J1.7 (DAT0), R3.1; also elsewhere on the board
SDDAT[1]: J1.8 (DAT1), R4.1; also elsewhere on the board
SDDAT[2]: J1.9 (DAT2), R5.1; also elsewhere on the board
SDDAT[3]: J1.1 (DAT3), R1.1; also elsewhere on the board
SDWP: J1.WP1 (WRITE_PROTECT), R7.1; also elsewhere on the board
SWDCLK: JP4.3; also elsewhere on the board
SWDIO: JP4.4; also elsewhere on the board
SWO: JP4.2; also elsewhere on the board
TRACECLK: JP4.9; also elsewhere on the board
TRACEDATA[0]: JP4.5; also elsewhere on the board
TRACEDATA[1]: JP4.6; also elsewhere on the board
TRACEDATA[2]: JP4.7; also elsewhere on the board
TRACEDATA[3]: JP4.8; also elsewhere on the board
VCC: C1.1, C2.1, J1.4 (VDD), J2.1, R1.2, R2.2, R3.2, R4.2, R5.2, R6.2, R7.2, R8.2; also elsewhere on the board
VDDANA: C6.1, C8.1, FL1.5, FL1.6, FL1.7, FL1.8; also elsewhere on the board
VDDCORE: C10.1, C11.1, L1.1; also elsewhere on the board
VDDIO: C5.1, C9.1, FL1.1, FL1.2, FL1.3, FL1.4; also elsewhere on the board
VDDIOB: C4.1, C7.1; also elsewhere on the board
VSW: L1.2; also elsewhere on the board

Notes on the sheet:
close to device (on every pin)
Pin headers optional

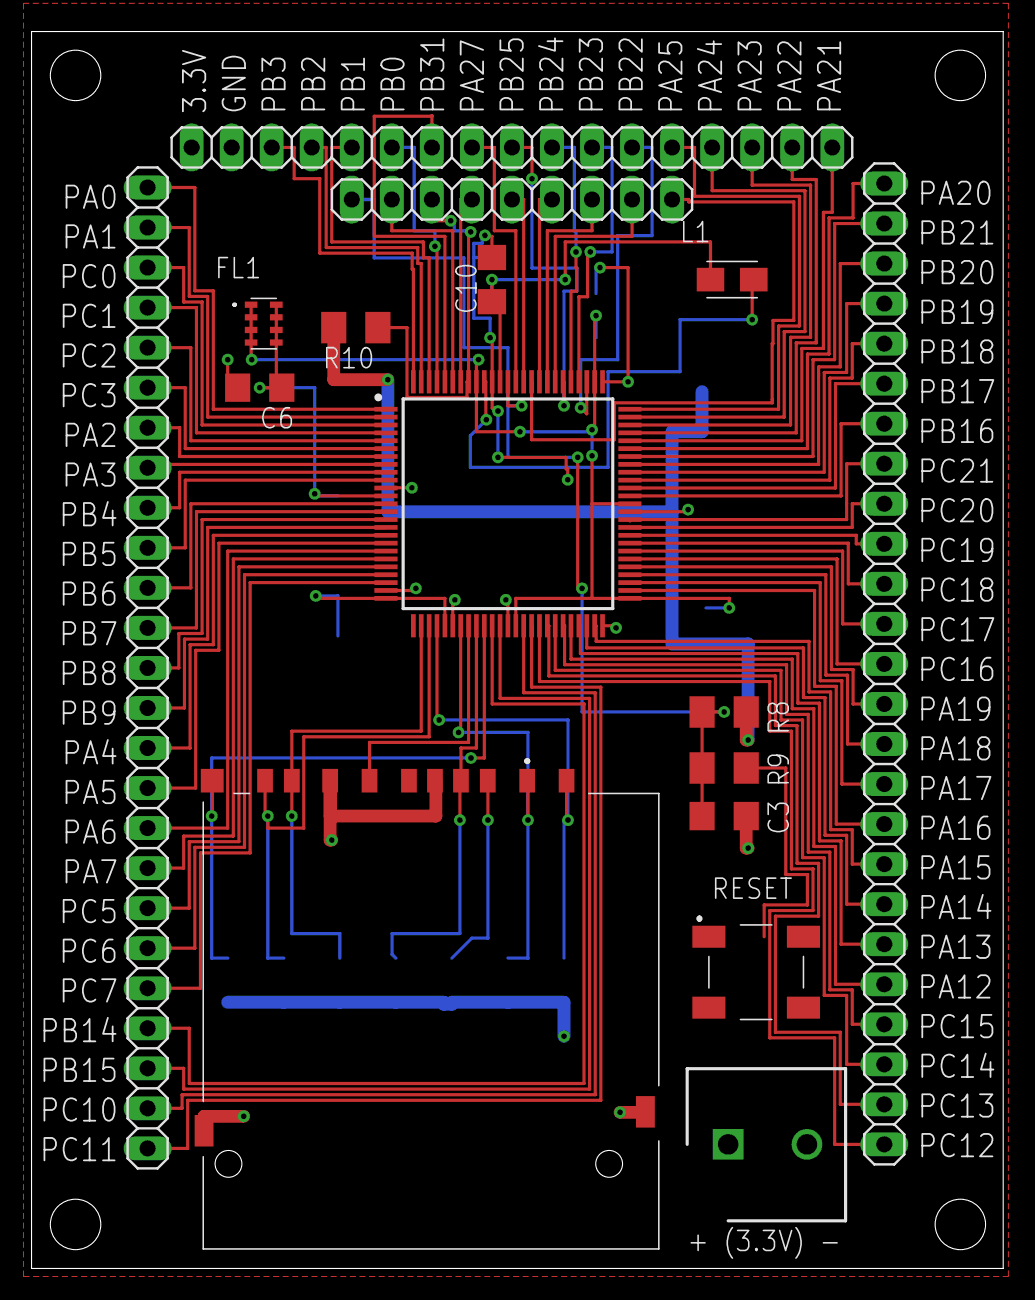
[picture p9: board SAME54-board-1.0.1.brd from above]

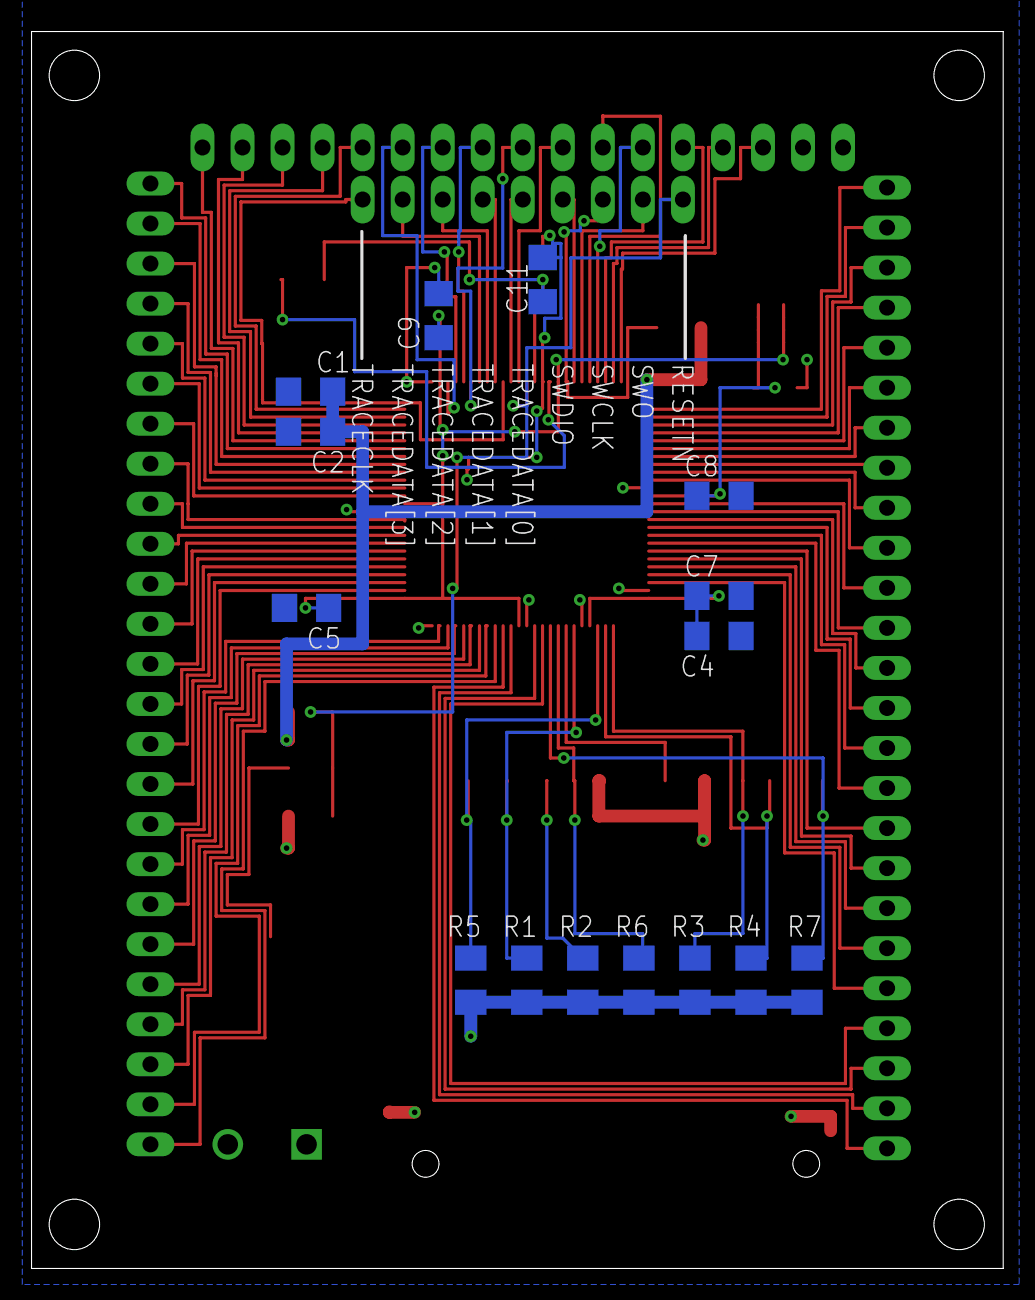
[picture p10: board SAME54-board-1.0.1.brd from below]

Board: 2 copper layers, 61.6 x 78.5 mm, 31 parts (15 on the bottom side), 90 nets.

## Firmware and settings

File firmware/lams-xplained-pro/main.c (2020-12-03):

#include "common.h"
#include "start.h"
#include "eeprom.h"
#include "scan.h"
#include "drivers.h"
#include "servo/servo.h"
#include "lidar/lidar.h"
#include "lams_sd.h"
#include "sd_mmc.h"

volatile uint32_t systick_count;
volatile uint32_t timer;
volatile uint8_t  status;

uint8_t menu_txt[] = "\r\n******** Enter choice ******** \r\n \
1. Reset device\r\n \
2. EEPROM\r\n \
3. Servo\r\n \
4. LiDAR\r\n \
5. LAMS SD\r\n \
6. 360-degree scan\r\n";

/** 
  * Application entry point
  */ 
int main(void)
{
	/* Initializes MCU, drivers and middleware */
	start_init();
	//delay_init(0);
	SysTick_Config(12000UL); /* 12M ticks/seconds / 1k ticks/second = 120000 */
	
	status = STATUS_IDLE;
	
	printf("\r\nLAMS_DEBUG = %u\r\n", LAMS_DEBUG);
	
	gpio_set_pin_level(LED_STATUS, 0);
	SERVO_set_angle(0);

	if (LAMS_DEBUG) {
		printf("\r\n\r\n========LiDAR Automated Mapping System (LAMS)========\r\n");

		while (1) {
			uint32_t user_selection = 0;

			printf("%s", menu_txt);
			
			if (scanf("%"PRIu32"", &user_selection) == 0) {
				/* If its not a number, flush stdin */
				fflush(stdin);
				continue;
			}
			
			printf("\r\nSelected option is %d\r\n", (int)user_selection);
			
			switch (user_selection) {
				case 1:
					NVIC_SystemReset();
					break;
				
				case 2:
					EEPROM_menu();
					break;

				case 3:
					SERVO_menu();
					break;
				
				case 4:
					LIDAR_menu();
					break;
				
				case 5:
					SD_menu();
					break;
				
				case 6:
					scan();
					break;
				
				default:
					printf("\r\nInvalid option \r\n");
					break;
			}
		} 
	} 
    /* LAMS_DEBUG = 0 */
    else {
		while (1) {
			scan();
		}
	}
	
	/* Execution should not come here during normal operation */
    return (EXIT_FAILURE);
}

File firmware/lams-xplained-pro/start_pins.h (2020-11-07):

#ifndef START_PINS_H_
#define START_PINS_H_

#include <hal_gpio.h>

/* SAME54 has 14 pin functions */
#define GPIO_PIN_FUNCTION_A 0
#define GPIO_PIN_FUNCTION_B 1
#define GPIO_PIN_FUNCTION_C 2
#define GPIO_PIN_FUNCTION_D 3
#define GPIO_PIN_FUNCTION_E 4
#define GPIO_PIN_FUNCTION_F 5
#define GPIO_PIN_FUNCTION_G 6
#define GPIO_PIN_FUNCTION_H 7
#define GPIO_PIN_FUNCTION_I 8
#define GPIO_PIN_FUNCTION_J 9
#define GPIO_PIN_FUNCTION_K 10
#define GPIO_PIN_FUNCTION_L 11
#define GPIO_PIN_FUNCTION_M 12
#define GPIO_PIN_FUNCTION_N 13

/* STDIO_REDIRECT */
#define PB24 GPIO(GPIO_PORTB, 24)
#define PB25 GPIO(GPIO_PORTB, 25)

/* LIDAR */
#define PA04 GPIO(GPIO_PORTA, 4) /* USART : Tx */
#define PA05 GPIO(GPIO_PORTA, 5) /* USART : Rx */
#define PB09 GPIO(GPIO_PORTB, 9) /* PWM : WO/1 */

/* SERVO */
#define PA07 GPIO(GPIO_PORTA, 7) /* PWM : WO/1 */

/* SDMMC */
#define PA20 GPIO(GPIO_PORTA, 20) /* SDCMD   */
#define PA21 GPIO(GPIO_PORTA, 21) /* SDCK    */
#define PB18 GPIO(GPIO_PORTB, 18) /* SDDAT/0 */
#define PB19 GPIO(GPIO_PORTB, 19) /* SDDAT/1 */
#define PB20 GPIO(GPIO_PORTB, 20) /* SDDAT/2 */
#define PB21 GPIO(GPIO_PORTB, 21) /* SDDAT/3 */
#define CARD_DETECT_0 GPIO(GPIO_PORTD, 20)
#define WRITE_PROTECT_0 GPIO(GPIO_PORTD, 21)

/* GPIO */
#define START_BTN GPIO(GPIO_PORTA, 27)
#define LED_STATUS GPIO(GPIO_PORTA, 6)
#define LED0 GPIO(GPIO_PORTC, 18)

#endif // START_PINS_H_

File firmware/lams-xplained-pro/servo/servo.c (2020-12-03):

#include "servo.h"
#include "common.h"
#include "drivers.h"
#include <peripheral_clk_config.h>

#define SERVO_PWM_PERIOD_us		3030
#define SERVO_PWM_MINIMUM_us	500
#define SERVO_PWM_MAXIMUM_us	2500
#define SERVO_PWM_COUNT			2273
#define SERVO_PWM_CC1_MIN		375 

static void SERVO_PWM_PORT_init(void);
static void SERVO_PWM_CLOCK_init(void);

extern volatile uint32_t timer;

/**
  *	Initializes PWM port for servo
  */ 
void SERVO_PWM_PORT_init(void)
{
	gpio_set_pin_function(PA07, PINMUX_PA07E_TC1_WO1);
}

/**
  *	Initializes PWM clock for servo
  */ 
void SERVO_PWM_CLOCK_init(void)
{
	hri_mclk_set_APBAMASK_TC1_bit(MCLK);
	hri_gclk_write_PCHCTRL_reg(GCLK, 
							   TC1_GCLK_ID, 
							   CONF_GCLK_TC1_SRC | (1 << GCLK_PCHCTRL_CHEN_Pos));
}

/**
  *	Initializes PWM for servo
  * 
  * Note: Initial servo position at 0 degrees 
  */
void SERVO_PWM_init(void)
{
	SERVO_PWM_CLOCK_init();
	SERVO_PWM_PORT_init();
	
	if (!hri_tc_is_syncing(TC1, TC_SYNCBUSY_SWRST)) {
		if (hri_tc_get_CTRLA_reg(TC1, TC_CTRLA_ENABLE)) {
			hri_tc_clear_CTRLA_ENABLE_bit(TC1);
			hri_tc_wait_for_sync(TC1, TC_SYNCBUSY_ENABLE);
		}
		hri_tc_write_CTRLA_reg(TC1, TC_CTRLA_SWRST);
	}
	hri_tc_wait_for_sync(TC1, TC_SYNCBUSY_SWRST);
	hri_tc_write_CTRLA_reg(TC1,
			  2 << TC_CTRLA_CAPTMODE0_Pos	/* Capture mode Channel 0: 2 */
			| 2 << TC_CTRLA_CAPTMODE1_Pos	/* Capture mode Channel 1: 2 */
			| 0 << TC_CTRLA_COPEN0_Pos		/* Capture Pin 0 Enable: disabled */
			| 0 << TC_CTRLA_COPEN1_Pos		/* Capture Pin 1 Enable: disabled */
			| 0 << TC_CTRLA_CAPTEN0_Pos		/* Capture Channel 0 Enable: disabled */
			| 0 << TC_CTRLA_CAPTEN1_Pos		/* Capture Channel 1 Enable: disabled */
			| 0 << TC_CTRLA_ALOCK_Pos		/* Auto Lock: disabled */
			| 1 << TC_CTRLA_PRESCSYNC_Pos	/* Prescaler and Counter Synchronization: 1 */
			| 0 << TC_CTRLA_ONDEMAND_Pos	/* Clock On Demand: disabled */
			| 0 << TC_CTRLA_RUNSTDBY_Pos	/* Run in Standby: disabled */
			| 4 << TC_CTRLA_PRESCALER_Pos	/* Setting: 4 - divide by 16 */
			| 0x0 << TC_CTRLA_MODE_Pos);	/* Operating Mode: 0x0 */
	hri_tc_write_CTRLB_reg(TC1,
			  0 << TC_CTRLBSET_CMD_Pos		/* Command: 0 */
			| 0 << TC_CTRLBSET_ONESHOT_Pos	/* One-Shot: disabled */
			| 0 << TC_CTRLBCLR_LUPD_Pos		/* Setting: disabled */
			| 0 << TC_CTRLBSET_DIR_Pos);	/* Counter Direction: disabled */
	hri_tc_write_WAVE_reg(TC1,3);			/* Waveform Generation Mode: 3 - MPWM */
	hri_tccount16_write_CC_reg(TC1, 0, SERVO_PWM_COUNT);	/* Compare/Capture Value: 2273 */
	hri_tccount16_write_CC_reg(TC1, 1, SERVO_PWM_CC1_MIN);	/* Compare/Capture Value: 375 */
	hri_tc_write_CTRLA_ENABLE_bit(TC1, 1 << TC_CTRLA_ENABLE_Pos);	/* Enable: enabled */
}

/**
  * Sets servo position to given angle
  * 
  * @param int : angle to set servo to
  */ 
void SERVO_set_angle(double angle)
{
	double angle_ratio = angle / 180.0;
	uint16_t pwm_spread = SERVO_PWM_MAXIMUM_us - SERVO_PWM_MINIMUM_us;
	double angle_us = SERVO_PWM_MINIMUM_us + (double)(angle_ratio * pwm_spread);
	uint16_t angle_val = (angle_us * SERVO_PWM_COUNT) / SERVO_PWM_PERIOD_us;
	
	if (!hri_tc_is_syncing(TC1, TC_SYNCBUSY_SWRST)) {
		if (hri_tc_get_CTRLA_reg(TC1, TC_CTRLA_ENABLE)) {
			hri_tc_clear_CTRLA_ENABLE_bit(TC1);
			hri_tc_wait_for_sync(TC1, TC_SYNCBUSY_ENABLE);
		}
	}
	hri_tc_wait_for_sync(TC1, TC_SYNCBUSY_SWRST);
	
	hri_tccount16_write_CC_reg(TC1, 1, angle_val);
	hri_tc_write_CTRLA_ENABLE_bit(TC1, 1 << TC_CTRLA_ENABLE_Pos);
}

/**
  *	Was hoping it would smooth the transitions -- these servos suck too much
  */
void SERVO_linear_transition_angle(double angle)
{
	double angle_ratio = angle / 180.0;
	uint16_t pwm_spread = SERVO_PWM_MAXIMUM_us - SERVO_PWM_MINIMUM_us;
	double angle_us = SERVO_PWM_MINIMUM_us + (double)(angle_ratio * pwm_spread);
	uint16_t val = 0, angle_val = (angle_us * SERVO_PWM_COUNT) / SERVO_PWM_PERIOD_us;
	
	while (val != angle_val) {
		if (!hri_tc_is_syncing(TC1, TC_SYNCBUSY_SWRST)) {
			if (hri_tc_get_CTRLA_reg(TC1, TC_CTRLA_ENABLE)) {
				hri_tc_clear_CTRLA_ENABLE_bit(TC1);
				hri_tc_wait_for_sync(TC1, TC_SYNCBUSY_ENABLE);
			}
		}
		hri_tc_wait_for_sync(TC1, TC_SYNCBUSY_SWRST);
		
		val = hri_tccount16_read_CC_reg(TC1, 1);
		if (val > angle_val)
			hri_tccount16_write_CC_reg(TC1, 1, --val);
		else if (val < angle_val)
			hri_tccount16_write_CC_reg(TC1, 1, ++val);
		hri_tc_write_CTRLA_ENABLE_bit(TC1, 1 << TC_CTRLA_ENABLE_Pos);
		
		timer = 1;
		while (timer);
	}
}

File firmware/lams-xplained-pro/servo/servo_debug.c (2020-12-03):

#include "servo.h"

uint8_t servo_menu_txt[] = "\r\n******** Enter choice ******** \r\n \
1. Back to main menu\r\n \
2. Set servo angle\r\n \
3. Set servo angle (linear transition)\r\n";

/**
  * Menu for servo command options in order to test angle adjustments with
  * servo
  */ 
void SERVO_menu(void)
{
	uint32_t user_selection = 0;
	uint32_t servo_angle	= 0;
	
	while (1) {
		printf("%s", servo_menu_txt);
		
		if (scanf("%"PRIu32"", &user_selection) == 0) {
			/* If its not a number, flush stdin */
			fflush(stdin);
			continue;
		}
		
		printf("\r\nSelected option is %d\r\n", (int)user_selection);
		
		switch (user_selection) {
			case 1:
				printf("\r\nReturning to main menu\r\n");
				return;
			
			case 2:
				printf("\r\nEnter angle >> ");
				scanf("%"PRIu32"", &servo_angle);
				printf("%"PRIu32"", servo_angle);
			
				if (servo_angle < 0 || servo_angle > 180) {
					printf("\r\nERROR: Invalid angle. Angle must be between 0 and 180\r\n");
					break;
				}
			
				printf("\r\nSetting servo angle to %0"PRIu32"\r\n", servo_angle);
				SERVO_set_angle(servo_angle);
				break;
			
			case 3:
				printf("\r\nEnter angle >> ");
				scanf("%"PRIu32"", &servo_angle);
				printf("%"PRIu32"", servo_angle);
				
				if (servo_angle < 0 || servo_angle > 180) {
					printf("\r\nERROR: Invalid angle. Angle must be between 0 and 180\r\n");
					break;
				}
				
				printf("\r\nSetting servo angle to %0"PRIu32" with linear transition\r\n", servo_angle);
				SERVO_linear_transition_angle(servo_angle);
				break;
			
			default:
				printf("\r\nInvalid option\r\n");
				break;
		}
	}
}

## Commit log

2020-05-19 Added power supply, reset button and SDHC interface
    [SAME54-board.sch]
2020-05-31 Designed board for all pre-determined peripherals needed.
    [SAME54-board.brd, SAME54-board.sch]
2020-05-31 Added drill holes and correct power supply mistake
    [SAME54-board.brd, SAME54-board.sch]
2020-05-31 Rotated R10 resistor text
    [SAME54-board.brd, SAME54-board.sch]
2020-05-31 Added LAMS logo
    [SAME54-board.brd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]
2020-05-31 Removed molex adapters and recplaed with single pin hole for each signal
    [SAME54-board.brd, SAME54-board.sch]
2020-05-31 New board design for better space managemnt
    [SAME54-board.brd]
2020-06-01 Added bill of materials
    [bill_of_materials.csv]
2020-06-01 Added label for Reset and increased hole dimensions to 3.2mm
    [SAME54-board.brd]
2020-06-01 Added Bill of Materials to README
2020-09-03 Starting new version of board. Bought Microchip development board--will only be printing final product
    [SAME54-board-1.0.1.brd, SAME54-board.brd, SAME54-board.sch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]
2020-09-28 Adding development board code and updated eagle files
    [SAME54-board-1.0.1.brd, SAME54-board-1.0.1.sch, SAME54-board.brd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]
2020-10-02 Working PWM TC channels for both servo and lidar
    [LAMS-POWER-SIM.DSN]
2020-10-02 Updated README with pin configs for lidar's USART
2020-10-02 Added voltage regulator to block diagram
2020-10-22 Added power and max20034 to schematic
    [SAME54-board.brd, SAME54-board1.0.2.sch]
2020-10-22 Updated schematic to include i/o, sd card, 12MHz clock
    [SAME54-board.sch]
2020-10-26 Finished custom SAME54 design. Ready to order
    [SAME54-board-1.0.2.brd, SAME54-board.brd, SAME54-board.sch]
2020-11-05 Functioning LIDAR scanning and servo movement. Moving onto SD read/write
2020-11-07 Added comments and moved lidar/servo files into separate folders for organization
2020-11-17 Added diskio and fatfs middleware for file writing
    [SAME54-board-1.0.3.brd, SAME54-board.brd, SAME54-board.sch]
2020-11-28 Reformatted to take averages of samples per scan point
2020-12-03 Adjusted servo to use double as angle measurements
